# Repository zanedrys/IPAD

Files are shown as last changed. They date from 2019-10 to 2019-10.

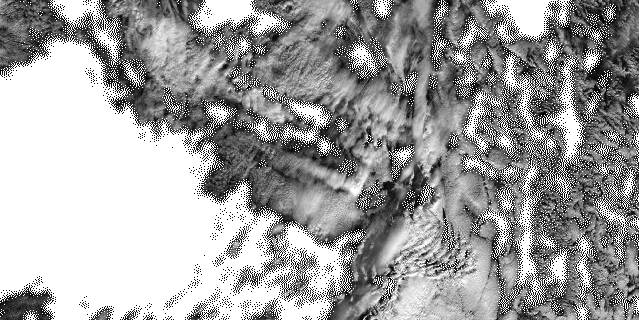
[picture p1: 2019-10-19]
Processing 2.2.1/processing-2.2.1/modes/java/examples/Books/Getting Started/media/clouds.gif

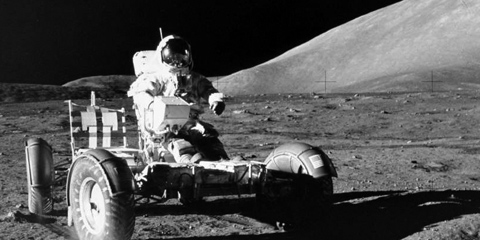
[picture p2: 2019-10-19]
Processing 2.2.1/processing-2.2.1/modes/java/examples/Books/Getting Started/media/lunar.jpg

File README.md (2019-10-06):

# IPAD
Interactive Programmable Arts Display

Getting Started - Testing Hardware,

  Below are the instructions to setup and test the hardware (CNC shield, Arduino, Stepper Motors, Drivers and various connections.

    1. Plug in necessary hardware, uno on arduino, 12v to cnc, steppers to cnc etc (See wiring diagram)
    2. Download and install Arduino IDE https://www.arduino.cc/en/main/software
    3. Download GRBL https://github.com/gnea/grbl/releases
    4. Download XLoader http://www.hobbytronics.co.uk/arduino-xloader
    5. Follow instructions to get GRBL on the Arduino/cnc
    6. Download Universal Gcode Sender https://winder.github.io/ugs_website/
    7. UGS should detect the CNC shield and any connected motors
    8. Plug and Play Away

Setting up a Gamepad/Joystick   
  Below are the methods to using a joystick/gamepad or any analog input method.
 
    1. Plug in necessary component
    2. Download and install Joys2Key https://joytokey.net/en/
    3. Download the library file 'JoyToKeyToPlotter.cfg' file (In repo)
    4. Import file to JoyToKey
    4. From within UGS (Universal Gcode Sender), use the joystick 

Setting up WASD Input Method (Any Input Is Possible)
  Below are instructions to create live Gcode to be sent to the UGS Command Line, highly configurable
  
    1. Download and Install AutoHotkey https://www.autohotkey.com/
    2. Download library file 'GcodeWASD.ahk' file (In repo)
    3. Run the file (Manipulate as desired for alternate inputs)
    4. From within UGS Command Line, use WASD to initiate movement

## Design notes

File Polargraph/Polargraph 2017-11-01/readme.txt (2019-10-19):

*  Polargraph Software
*
*  Written by Sandy Noble
*  Released under GNU License version 3.
*  http://www.polargraph.co.uk
*  https://github.com/euphy/polargraph

10th May 2017

This is the source code for the Polargraph software. 
It contains:

Controller v2.4.2
---------------

Binary (compiled) versions of the controller for

- 32 bit linux
- 64 bit linux
- 32 bit Windows
- 64 bit Windows
- MacOS

Along with source code for the controller in the processing-source 
folder.

It also includes the required Processing libraries (geomerative, Controlp5, 
Diewald CV kit) that the controller uses.  These are not necessarily
the most recent versions, but they are the versions that work.

Processing Libraries should be copied into the libraries subfolder in 
your Processing sketchbook folder.

This is written and compiled under Processing v2.2.1.  
It does not work in Processing 3.

Firmware
--------

* Server v1.2.1 for regular Polargraph (UNO, MEGA) machines.
* Server v1.4 for PolargraphSD machines.

Code has been tested in Arduino IDE 1.6.7.

The arduino-source folder has the code for the firmware that should 
be uploaded to your arduino.  There are currently two supported versions:

- polargraph_server_a1 for Arduino UNO- or MEGA-based machines, based on 
  Adafruit motorshields, or with serial stepper drivers (eg Easydriver, 
  stepstick etc) or signal amplifiers.

- polargraph_server_polarshield for Arduino MEGA 2560 running with 
  an attached Polarshield, serial stepper drivers and LCD touchscreen.

Each version is in it's own folder along with a precompiled .hex that
can be loaded directly using something like XLoader (some info about this
https://github.com/euphy/polargraph/wiki/Uploading-precompiled-binary-hex-files)

In the arduino-source folder there is also a libraries folder that
has all the arduino libraries that you will need to compile the 
firmware.

- AccelStepper
- AFMotor (for those using the Adafruit motor shield v1)
- Adafruit_MotorShield (for those using the Adafruit motor shield v2)
- UTFT (for the polarshield)
- UTouch (for the polarshield)

UTouch sometimes benefits from calibration, so if you find your 
touchscreen is not responding properly to your touch, you might 
need to do that.  The calibration figures that are in there already 
are ok for my ITDB02-2.4 screens.

The arduino libraries should be copied into your arduino sketch folder.

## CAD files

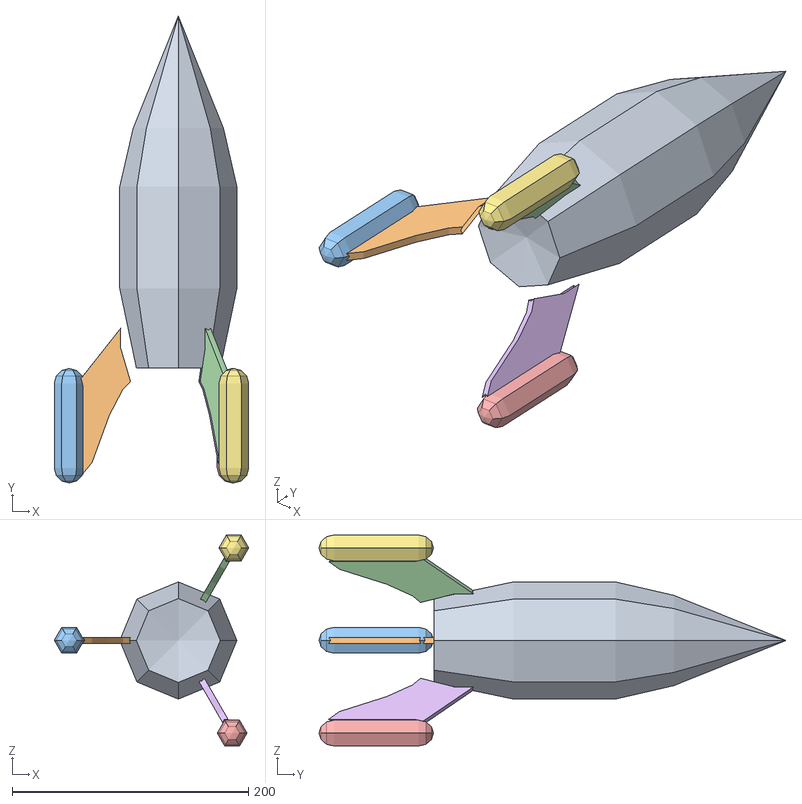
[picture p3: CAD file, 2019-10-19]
Processing 2.2.1/processing-2.2.1/modes/java/examples/Basics/Shape/LoadDisplayOBJ/data/rocket.obj
164.8 x 395.7 x 178.8
Rocket
wing01
reactor01
wing02
reactor03
wing03
reactor02

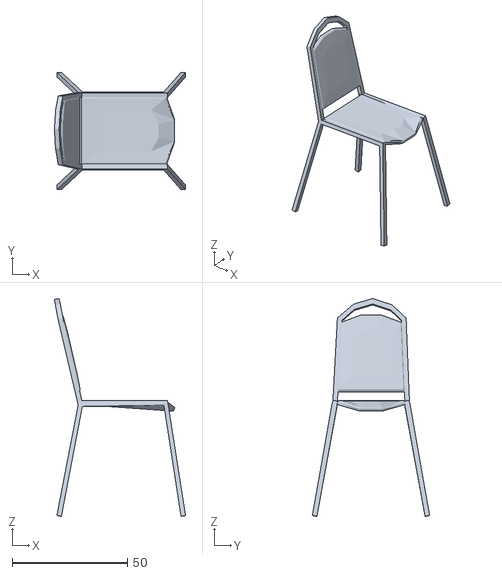
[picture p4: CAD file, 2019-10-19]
Processing 2.2.1/processing-2.2.1/modes/java/examples/Books/Processing Handbook/Extensions/3D/Ex_05/data/chair.obj
56.8 x 50.7 x 94.4

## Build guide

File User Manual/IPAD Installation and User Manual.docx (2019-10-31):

# Interactive Programmable Arts Display

# V Plotter Installation and User Manual

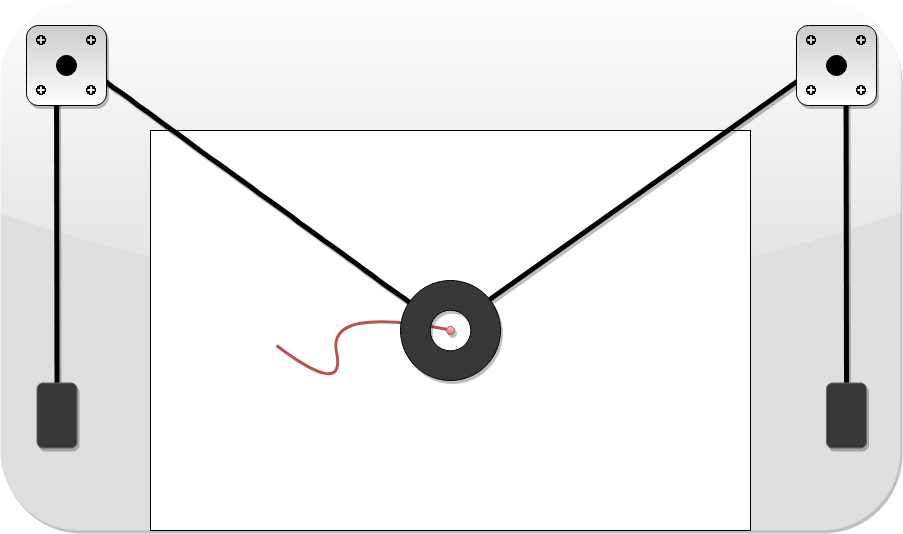
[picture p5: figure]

Version | Date | Description | Author
1 | 24/10/2019 | Initial creation | Zane Drysdale – zjdrysdale@gmail.com
2 | 26/10/2019 | Firmware and software Instructions update | Zane Drysdale – zjdrysdale@gmail.com Corey Page – Corey.t.page@outlook.com.au
3 | 27/10/2019 | 5.1 .1 Values update | Corey Page – Corey.t.page@outlook.com.au
4 | 27/10/2019 | Team Signoff | Zane Drysdale – zjdrysdale@gmail.com Corey Page – Corey.t.page@outlook.com.au Franklin Moon – Franklin.m.moon@gmail.com Zinan Chen–

# 1 Introduction and Purpose

A V Plotter is a drawing robot which uses two motors to move a hanging writing implement across a drawing surface.

The purpose of this document is to provide a complete end-to-end guide for the creation of the V Plotter, including hardware requirements as well as software installation, configuration, usage, and troubleshooting.

This complete solution is reliant upon three distinct yet interrelated subsets. The hardware which is the physical canvas, motor and electronics setup, the Windows/Linux software which handles end user input, and the Arduino firmware which interprets commands from the software and controls the motors. This document details the installation and configuration of all three of these subsets as part of the overall solution.

This document is targeted towards anyone who wishes to set up the V Plotter and has basic computing knowledge. This guide presumes that you are setting up the V Plotter with the hardware as provided, however, additional notes cover alternative implementations or possible modifications or options.

Some steps require caution, this information is in red.

# 2 Hardware

The physical aspects of the V Plotter consist of the motors and the board that they are mounted to, as well as the belts and physical electrical and computer hardware. The below diagram details at a high level the basic physical components:

The

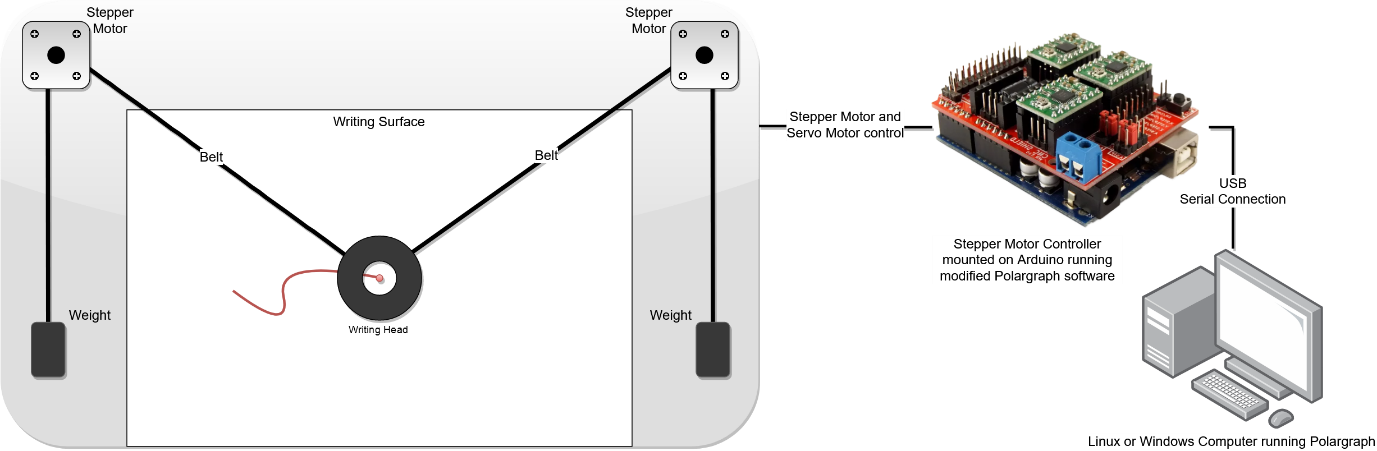
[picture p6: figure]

Figure 1: Overall V Plotter setup

## 2.1 Components

The V Plotter as delivered consists of the following required and supplied hardware components:

- Machine surface – overall surface that the motors are mounted to
- Writing surface
- 2 NEMA stepper motors. 200 steps per revolution.
- Official Arduino UNO loaded with modified Polargraph firmware
- Stepper Motor Controller – Specifically the Protoneer CNC Shield V3: https://blog.protoneer.co.nz/arduino-cnc-shield
- 12V 1 Amp DC Power supply
- Belts and suitably toothed and spindled gears
- Microsoft Windows based computer running Polargraph
- 3D printed motor mounts
- Associated wiring for motors

The main components are further detailed as follows:

### 2.1.1 Arduino UNO

The Arduino is responsible for translating the commands sent over USB from the Polargraph application into electrical signals to the stepper motor controller. As such, the Arduino and stepper motor controller are highly dependent upon one another.

### 2.1.2 Stepper Motor

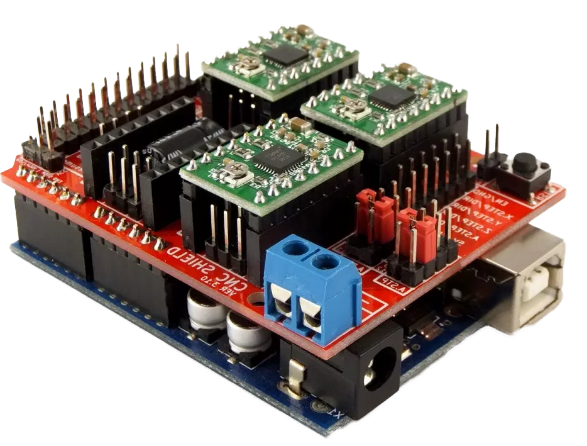
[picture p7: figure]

The stepper motor driver is responsible for actuating the motors as required, and electronically separating logic and power for safety and durability. The Protoneer stepper motor is typically used for three-axis CNC machines. The Protoneer stepper motor provided is designed to be directly compatible with an Arduino UNO, and sits directly on top, interfacing with the Arduino outputs directly, as shown in Figure 2:

### 2.1.3 Power Supply

Figure 2. Stepper Motor Controller mounted on top of an Arduino UNO

Responsible for providing power to the stepper motor controller. Simply plugs into the DC female terminal on the Arduino, also visible in Figure 2.

## 2.2 Hardware Setup

This section details the physical installation of the components.

The physical installation is provided pre-assembled and will require minimal setup or extra assembly. However, if assembly is required:

### 2.2.1 Writing Head

The writing head is the device which sits hung across the drawing surface. It holds the pen or other writing implement and is supported and moved by the belts.

1. Place the pen into the centre of the writing head and tighten the threads to secure it in place. It is imperative that the tip of the pen only minimally protrudes from the underside of the writing head to improve accuracy
2. Affix the belts around the mounts on the corners of the writing head
3. Mount the servo motor into the top of the writing head

### 2.2.2 Stepper Motors

The motors are responsible for moving the writing head by lengthening or shortening the amount of belt between the motor and writing head.

1. Ensure that the motors are bolted to their mounts
2. Bolt each mount to the machine surface
3. Plug in the motor-end of the supplied wiring
4. Run the belt atop the gear to form the overall ‘V’ shape, as in Figure 1
5. Affix the weights to the end of the belt

### 2.2.3 Servo Motor

The servo motor is responsible for raising and lowering the pen off the page. It is connected to the stepper motor controller in our solution. Refer to Appendix 3 for the wiring diagram.

1. Plug the RED wire of the servo into the +5V output on the Protoneer. This is the power for the servo.
2. Plug the BROWN wire of the servo into the BLACK side of the CooEn pin on the Protoneer. This is the ground for the servo.
3. Plug the ORANGE wire of the servo into the WHITE side of the CooEn pin on the Protoneer. This is the signal for the servo.

### 2.2.4 Arduino and Stepper Motor Controller

As detailed in their sections above, the Arduino and stepper motor controller are responsible for receiving commands over USB and driving the motors. The Protoneer stepper motor controller sits directly atop the Arduino as shown in Figure 2. Refer to Appendix 3 for the wiring diagram.

1. Sit the Protoneer stepper motor controller atop the Arduino as depicted in Figure 2.
2. Plug the other end of the previously attached motor wires into the stepper motor controller X and Y outputs, such that the left motor is plugged into the ‘X’ output, and the right motor is plugged into the ‘Y’ output. Take note of the direction that the cables are plugged in; the lip on the connector is facing the motor shields of their respective outputs, as visible below in Figure 3

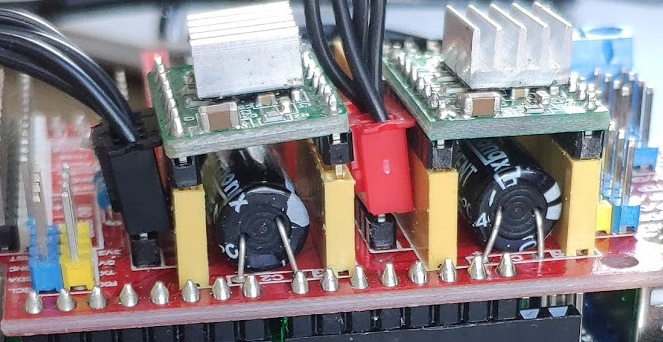
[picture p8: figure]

Figure 3: Motor wiring on stepper controller

### 2.2.5 Power Supply

Caution: Although the supplied power supply has a low risk of electric shock, be careful to ensure that it is not shorted, it could hurt or even worse break something.

Caution: Never cut power to the stepper motor controller while the V Plotter is in operation or holding the motors’ position, as it can damage the stepper motor controller.

- Plug the output of the power supply into the female DC power input of the Arduino, as visible in Figure 2

## 2.3 Modifications or Customizations

The V Plotter is designed to be easily modular and flexible to alternative physical implementation with only a software reconfiguration required. However:

- Increasing the size of the machine considerably may require motors with additional torque and larger sprockets, and possibly in turn a higher-output power supply.
- Alternative stepper motor controllers are possible; however, as detailed in the below section, the Arduino firmware may require customization to modify the output pins to match the alternative stepper motor controller.

# 3 Firmware

The firmware is responsible for receiving the commands from the Polargraph application running on a computer and sending the correct electrical signals to drive the stepper motor controller. It interprets ASCII commands sent over the USB connection from the Polargraph application running on a computer.

This solution uses the Polargraph firmware and associated end user application from polargraph.uk. This step covers the firmware half.

The Polargraph firmware expects an alternative stepper motor controller and therefore our solution includes a modified version of the firmware that supports the Protoneer stepper motor controller. 3.2 details how to install this modified firmware, or you can follow 3.3 to modify the firmware from source.

This step details how to modify and load the firmware on the Arduino if required. As delivered, the Arduino is already loaded with the modified firmware.

## 3.1 Requirements

The modified firmware as delivered is intended for an Arduino UNO and the Protoneer stepper motor controller pairing. The firmware can be installed from a Windows, Linux, or Mac computer. The modifications made to the source include:

- Manual configuration of the stepper motor output pins on the Arduino to match the expected inputs on the Protoneer stepper motor controller.
- Manual configuration of the Pen lift pin, to allow the signal to be passed through to Protoneer stepper motor controller via the “Coolant Engage” pin, using the A3 pin on the Arduino.

It would be best to clone or download the IPAD repo (http://github.com/zanedrys/IPAD) to ensure that you have the firmware and software required for the following steps.

## 3.2 Installation – Custom Firmware

1. Firstly, install the Arduino IDE from arduino.cc for your platform
2. Download the modified firmware from GitHub: https://github.com/zanedrys/IPAD/tree/master/Polargraph/Polargraph%202017-11-01/modified%20arduino-source, or even better clone the repository for future use.
3. Included are the Arduino libraries that are required and known to work to compile the source code. Copy the files in the “libraries” folder into your Arduino Sketch directory, or alternatively add them to your Libraries from the Arduino IDE.
4. Open the “polargraph_server_a1” sketch in the Arduino IDE.
5. Verify the sketch to ensure that it compiles:

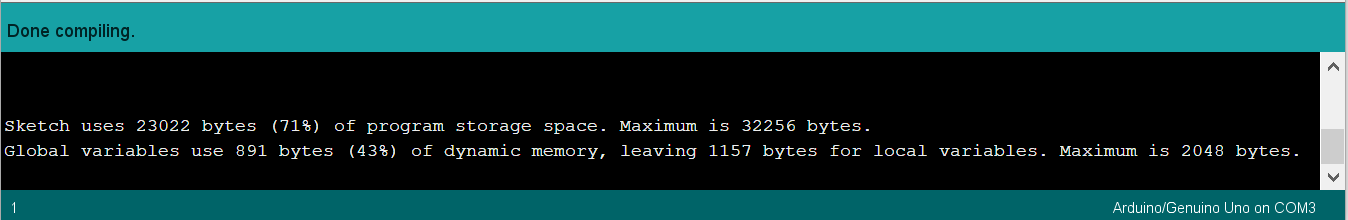
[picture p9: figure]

6. Plug the Arduino into your computer with a USB cable, and wait until the drivers are installed.
7. Within the Arduino IDE, check that your Arduino is connected. Under ‘Tools’ -> ‘Port’, the Arduino should be listed.
8. Click the arrow to upload the firmware to the Arduino:

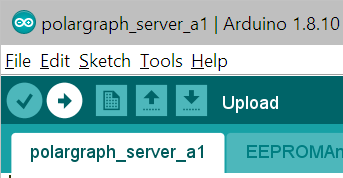
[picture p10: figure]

9. The Arduino IDE should tell you that the firmware was successfully flashed.

## 3.3 Modifying firmware from source

This step is not necessary if you flashed the custom firmware from the previous step.

If you wish to modify the firmware yourself, the Polargraph firmware can be modified to work with a variety of stepper motor controllers:

- The Adafruit Motorshield v1 and v2
- Generic serial stepper drivers
- Four-wire signal amplifiers

By default, the source Polargraph firmware is designed to be used with an Adafruit stepper motor. The Protoneer stepper motor controller used in this solution is a generic serial stepper driver at core. Therefore, the source firmware must be modified to work with the Protoneer. Below are the steps required to modify the firmware from source with examples for the Protoneer controller in particular:

1. Download the source Polargraph firmware from GitHub: https://github.com/euphy/polargraphcontroller/releases/
2. Install the Arduino IDE from arduino.cc for your platform
3. Included within the “arduino_source” directory are all the files required. Copy the files in the “libraries” folder into your Arduino IDE Sketch directory, or alternatively add them to your Libraries from the Arduino IDE
4. Open the “polargraph_server_a1.ino” sketch in Arduino IDE. It is commented well with instructions. Instructions specifically for the Protoneer follow:
5. Specify the custom motor driver:
  a. Comment out lines within section 3i, as this solution does not use the Adafruit:

// i. Adafruit Motorshield v1. The original, and still the best.

// #define ADAFRUIT_MOTORSHIELD_V1

// #include <AFMotor.h>

  b. Uncomment out lines within section 3ii, as this solution uses a discrete stepper driver:

// iii. Using discrete stepper drivers? (eg EasyDriver, stepstick, Pololu gear)

// ----------------------------------------------------------------------------

// Don't forget to define your pins in 'configuration.ino'.

#define SERIAL_STEPPER_DRIVERS

  c. Change the output pin for the Pen Lift to A3 as in the following block of code.

// Pen raising servo

Servo penHeight;

const int DEFAULT_DOWN_POSITION = 90;

const int DEFAULT_UP_POSITION = 180;

static int upPosition = DEFAULT_UP_POSITION; // defaults

static int downPosition = DEFAULT_DOWN_POSITION;

static int penLiftSpeed = 3; // ms between steps of moving motor

const byte PEN_HEIGHT_SERVO_PIN = A3; //Change the servo pin to A3, to pass through to the coolant enable pin.

boolean isPenUp = false;

  d. Configure the Arduino output pins in ‘configuration.ino’ as follows, to match the Protoneer. To see where we got these pins are from, refer to Appendix 2 for the Protoneer pinout:

#ifdef SERIAL_STEPPER_DRIVERS

#define MOTOR_A_ENABLE_PIN 8

#define MOTOR_A_STEP_PIN 2

#define MOTOR_A_DIR_PIN 5

#define MOTOR_B_ENABLE_PIN 4

#define MOTOR_B_STEP_PIN 3

#define MOTOR_B_DIR_PIN 6

AccelStepper motorA(1,MOTOR_A_STEP_PIN, MOTOR_A_DIR_PIN);

AccelStepper motorB(1,MOTOR_B_STEP_PIN, MOTOR_B_DIR_PIN);

#endif

6. Follow the instructions for 3.2 Installation – Custom Firmware to install the modified firmware.

# 4 Software

This solution uses the Polargraph firmware and associated end user application from polargraph.uk. This step covers the installation of the application half.

The application is responsible for providing an end-user graphical interface and sending commands to the firmware running on the Arduino. It can load vector and bitmap images.

## 4.1 Requirements

The Polargraph application is written in Processing 2.2.1 and requires the Java Runtime Environment to run.

Processing is compatible with Windows (32/64 bit), Linux (32/64 bit), and Mac OSX. Therefore, Polargraph can only run on those platforms.

## 4.2 Installation

Included in the GitHub repository are pre-compiled versions of the Polargraph application: “IPAD\Polargraph\Builds”.

1. Copy the suitable folder for your system to a suitable location. The binaries are available in Linux and Windows, each in 32-bit or 64-bit versions. The Windows 64-bit version includes its own Java Runtime Environment, otherwise ensure that you have the Java Runtime Environment installed.
2. Run the suitable binary for your system.
3. After a minute or so on first run the application should start. If it doesn’t and Java is installed, it may be necessary to run it from source. Refer to section 4.3 below:

## 4.3 Run from Source

Java, Windows, and Processing may not work as expected on some machines. In this case the Polargraph software can be run from source code. This method can also be used if the Polargraph software receives an update, or if you wish to modify the source code or debug the application.

1. Download Processing 2.2.1 from processing.org (https://processing.org/download/?processing). Ensure to download the version with Java included. Alternatively, Processing 2.2.1 is included in the GitHub repo.
2. Install Processing to a suitable folder and run it. Processing calls applications “sketches”, and your Sketchbook folder is where they are stored. On Windows, it is the Processing folder within the user’s Documents folder. If you need to find out where your sketchbook is, then you can open Processing, and go file->preferences and it'll tell you your Sketchbook location at the top of the dialog box. The folder might not get created until you run Processing once.
3. Download code from the repo https://github.com/euphy/polargraphcontroller/releases/latest and download the package. Alternatively download the version from our repo: https://github.com/zanedrys/IPAD/tree/master/Polargraph/Polargraph%202017-11-01/processing-source
4. Copy the entire ‘polargraphcontroller’ folder into your Processing sketch folder. E.g. ‘Documents/Processing/polargraphcontroller’
5. Copy the folders within the ‘Processing libraries (https://github.com/zanedrys/IPAD/tree/master/Polargraph/Polargraph%202017-11-01/processing-source/Processing%20libraries)’ folder into the Processing ‘libraries’ folder, not the folder itself.
6. The folder structure therefore after these changes (shown in bold) should look like:
  - Processing/
    - libraries/
      - ControlP5/..
      - diewald_CV_kit/..
      - geomerative/..
    - polargraphcontroller/
7. From the ‘File’-> ‘Sketchbook’ option in Processing, open the polargraphcontroller sketch:

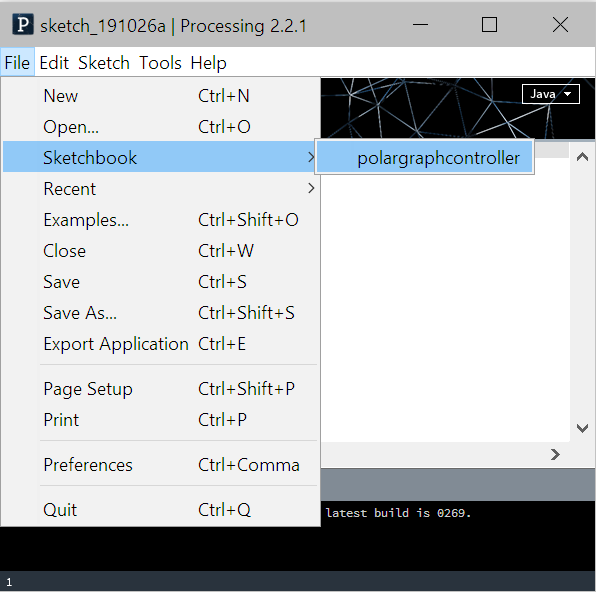
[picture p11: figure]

8. Run the sketch and the Polargraph application should start.

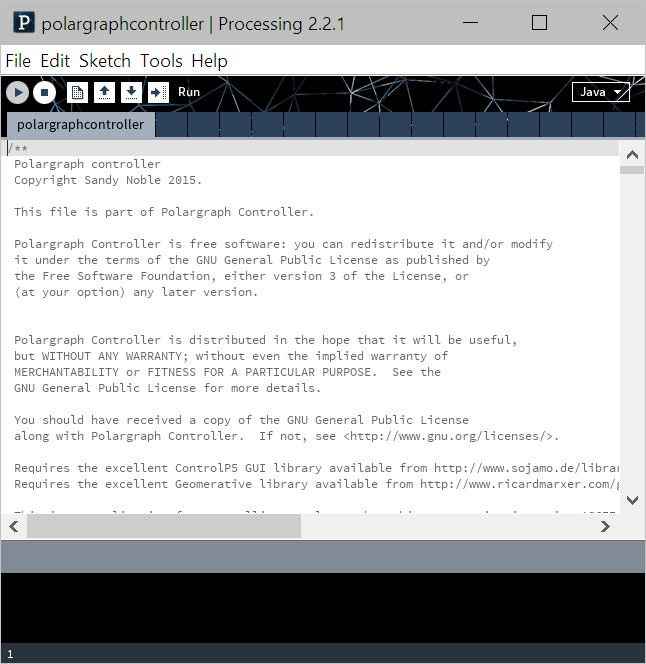
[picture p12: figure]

9. Congratulations, the Polargraph application should now be running.

## 4.4 Compile from Source

After completing the steps in 4.3 – Run from Source, you can create your own build of the Polargraph application. This might be especially helpful if the pre-compiled version supplied did not start, and you had to run the application from source as above.

1. Open the sketch in Processing as detailed in 4.3 – Run from Source
2. Go ‘File’ -> ‘Export Application’:
3. Choose the platforms to compile for, and whether to include Java in the Windows 64-bit build if applicable. Click Export:

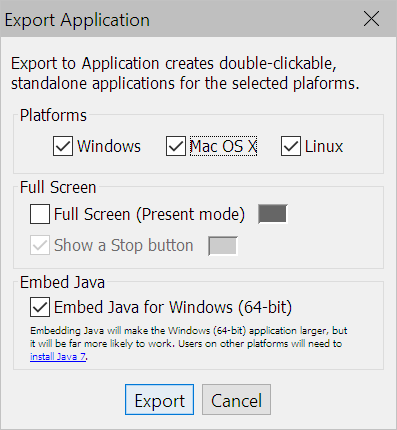
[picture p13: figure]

# 5 Configuration

Now that the hardware is set up, the Arduino is running the firmware, and the software is running on computer, it is time to set up the Polargraph software to finally draw. Below is a checklist to go through to ensure that the V Plotter is ready.

Pre-Flight Checklist:

1. Check that the board and surface is set up, and the belts and writing head are set up.
2. Check that the motors are correctly plugged into the motor controller.
3. Check that the stepper motor is correctly plugged into the top of the Arduino.
4. Ensure that the Arduino is connected to your computer over USB, and that it is powered on.
5. Plug in the power adaptor and turn the switch on.

## 5.1 Configure Polargraph application

### 5.1.1 Physical Attributes

The Polargraph application needs to know the following information about the physical setup to draw accurately. This information is entered into the ‘Setup’ page, as shown in 6.1.2 – Setup Page.

- Steps per Rev: How many steps your stepper motors require to make a complete revolution. As delivered, the motors require 200 steps per revolution.
- mm per rev: How much belt is let in or out per revolution of the stepper motor. As delivered, this is 50 mm. To calculate this yourself simply find the circumference of your sprocket.
- Motor Step Multiplier: How many micro-steps your motor controller makes per full step of the motor. Stepper motor controllers can increase the resolution of your motors by using micro stepping. As delivered, the Protoneer is not performing micro stepping.
- Machine Width in mm: The physical width of the machine, refer to Figure 4: Machine Dimensions. As delivered, this is 724 mm.
- Machine Height in mm: The physical height of the machine. Refer to Figure 4: Machine Dimensions. As delivered, this is 480 mm.
- Page Width: The width of the drawing area available to be drawn on. Naturally, this must be smaller than your machine width. Allow for some buffer as the V Plotter will be increasingly less accurate the closer it attempts to draw to the motors. As delivered, this is 600mm
- Page Height. The height of your page. This must also be small than your machine height and have buffer between the height of the motors and the top of the page. As delivered, this is 400mm.
- Page Pos X: Where the page sits horizontally. Polargraph can set this to be in the centre of your machine. As delivered, this is 150 mm.
- Page Pos Y: How far below the machine top that the page sits. Again, this cannot be too close to the top of the machine. As delivered, this is 130 mm.
- Home Pos X/Y: Where the physical position of the writing implement is aligned with the start position. This is required so that Polargraph knows where the writing head is. Polargraph can automatically set this to be the top centre of your page. It can be wherever you like, if you can accurately manually place the writing head in that location.
- Motor Max Speed: The maximum speed that the machine will move the motors. Have this too low, and the motors will move very slowly, and your drawing will take a long time to complete. Have this too high, and you may encounter the belt hopping on the sprocket, which will ruin your image. 100
- Motor Acceleration: How quickly the motors will accelerate up to the Motor Max Speed. Have this too high and the belt may hop on the sprocket while the machine is accelerating from a stop, or from changing direction. Have this too low, and your machine may never reach its Motor Max Speed. 80
- Pen Up Position: The angle that the machine will hold the servo at when the pen is up. 70mm
- Pen Down Position: The angle that the machine will hold the servo at when the pen is down. 187 mm
- Pen Thickness: Determines how many lines the V Plotter can fit into an area. If you have a pixel that is 20mm square, and you have a 1mm pen tip, then you can only fit a maximum of 20 lines in before it's at its maximum density. Adding more ink then won't make it any darker. You can change the pen width on the setup tab, by changing the value of pen tip size and clicking send pen tip size. The tip size is not saved in the machine, it needs to be resent every time the machine is restarted, which is why the value is pre-loaded in the queue when you restart the controller.

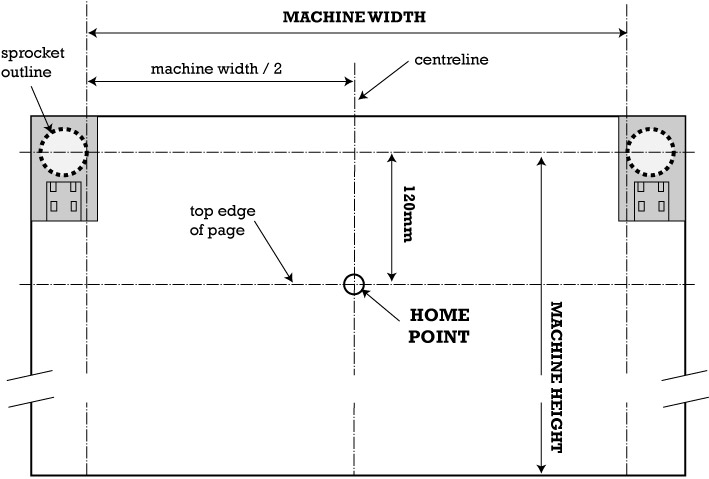
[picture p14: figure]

Figure 4: Machine Dimensions

### 5.1.2 COM Configuration

The Polargraph application communicates with the Arduino firmware over a USB COM port. To set the COM port in the Polargraph application, go to ‘Setup’->’Serial Connection’, and choose your COM port. It can be best to restart Polargraph after changing this option.

The Polargraph application will display ‘Polargraph Ready! (Uno)’ when the Arduino is successfully connected:

# 6 User Guide

This section of the Manual will cover the usage of the application and presumes that the machine is set up with the information presented thus far.

## 6.1 Navigating the Application

The Polargraph application is used through the following three views:

### 6.1.1 Input:

Input vectors, drawing and lines to be drawn.

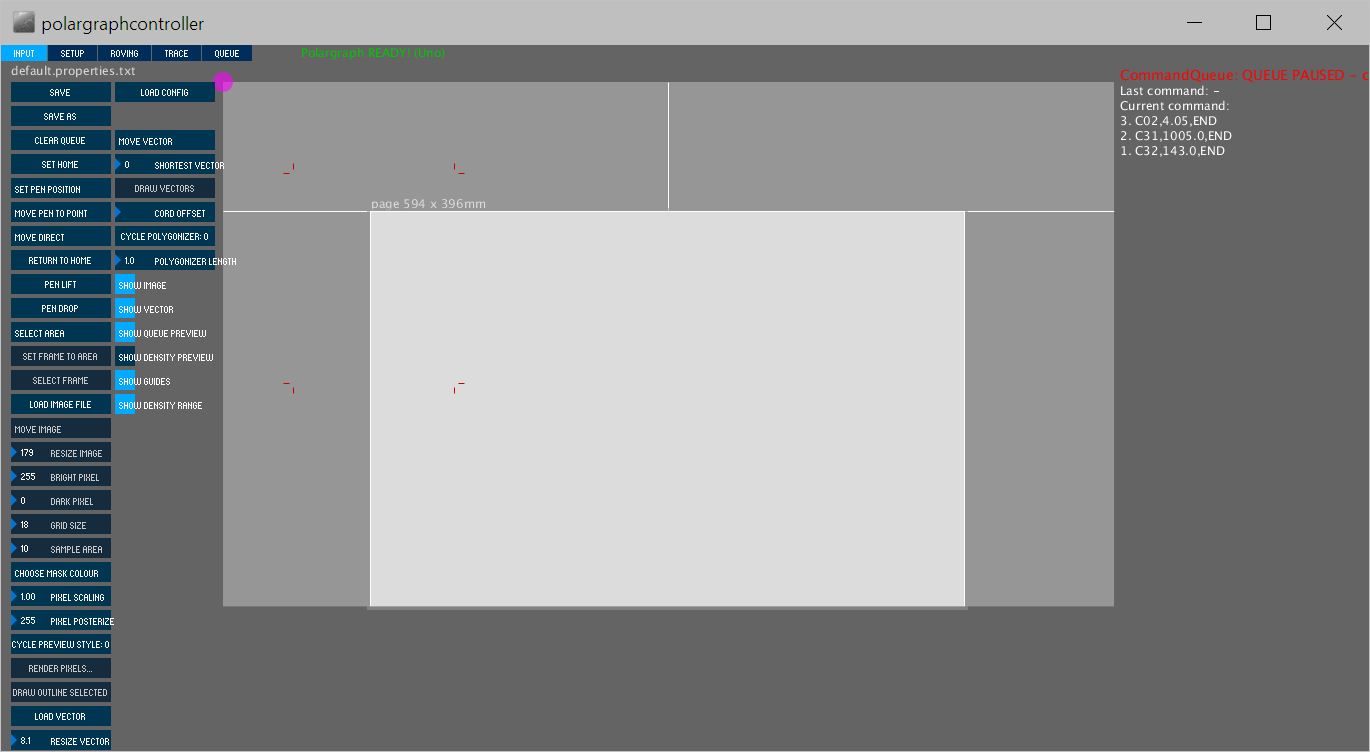
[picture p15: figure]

### 6.1.2 Setup

Sets up the machine configuration.

- Input the values from 5.1 – Configuring Polargraph Application into this screen.
- Ensure to click ‘Upload Machine Spec’ with the queue running to send the updated settings to the Arduino.
- You can ‘Centre Page’ to place the page in the middle of the machine.
- You can ‘Centre Homepoint’ to place the home position at the top middle of the page.
- You can also export and load these settings with ‘Save As’ and ‘Load Config’.
- Ensure to click ‘Save’ to save these settings for the Polargraph application.

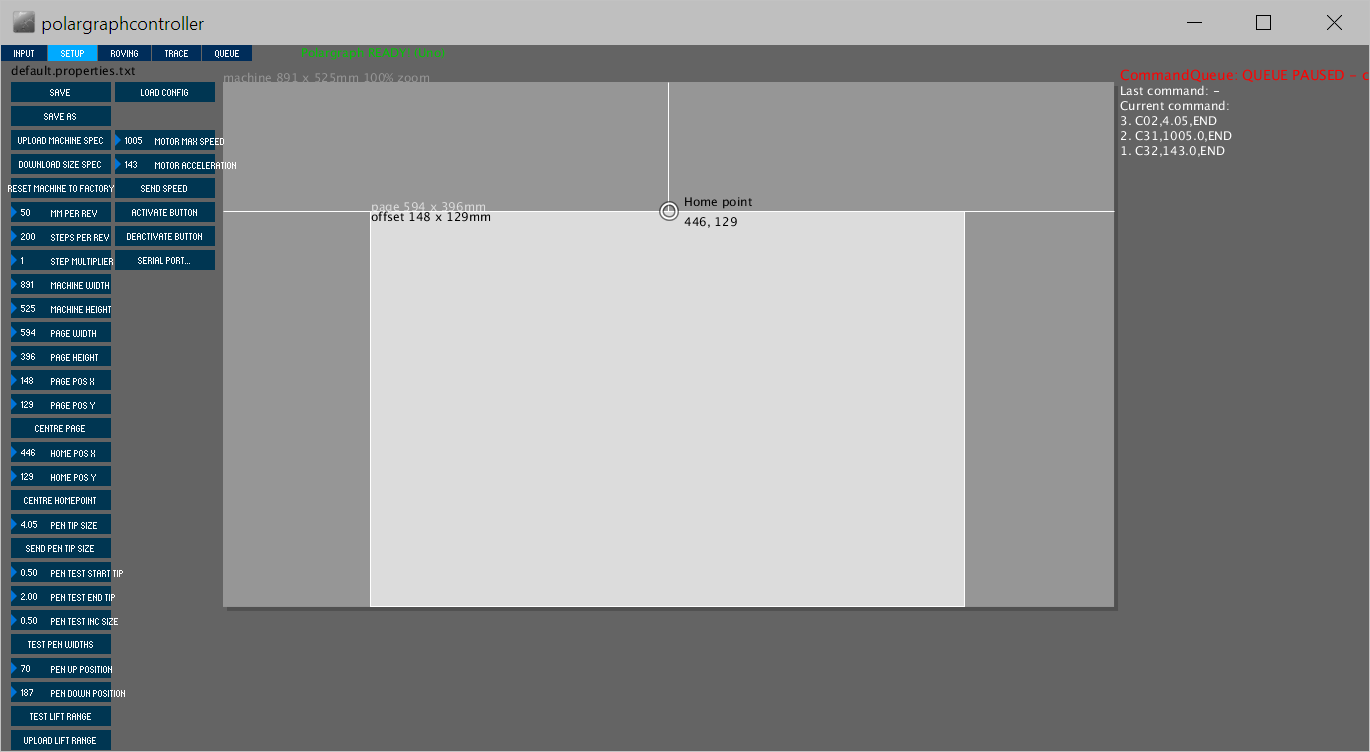
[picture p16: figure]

### 6.1.3 Trace

Used to convert bitmaps to vectors.

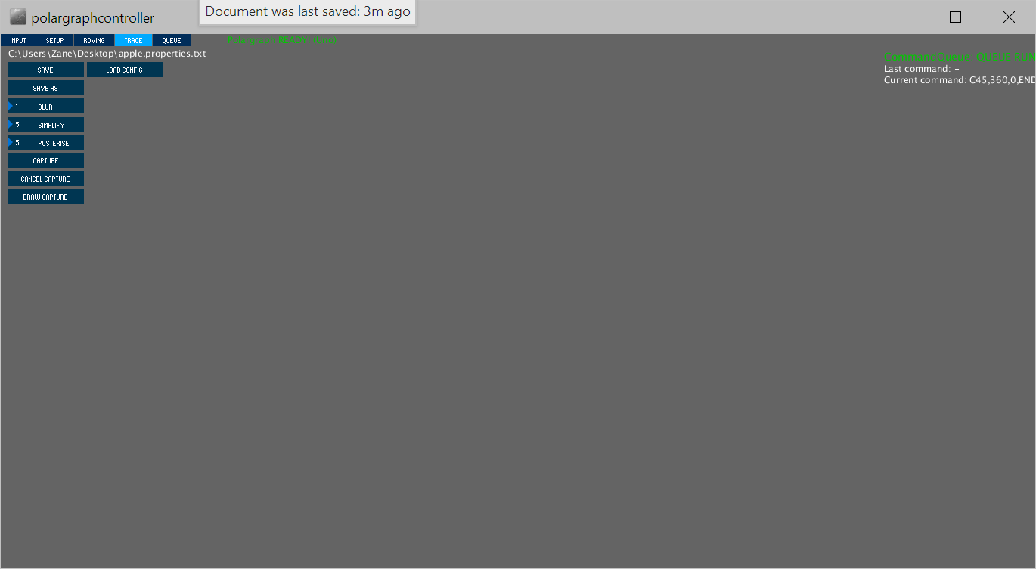
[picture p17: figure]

### 6.1.4 Queue

Used to export and import the command queue.

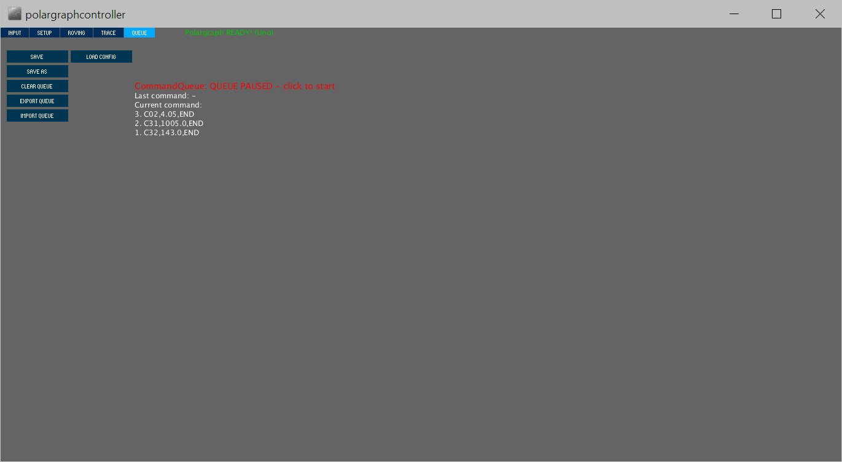
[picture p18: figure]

## 6.2 Drawing

### 6.2.1 Queue

As visible in the screenshots above, there is a queue to the right. This list contains the list of commands that will be sent to the Arduino. On start-up, this queue is in a Paused state, and will not send commands to the Arduino. To un-pause it, simply click the Command Queue text.

### 6.2.2 Homing

The V Plotter needs to be homed on start-up, so that Polargraph knows the physical location of the writing head. Manually move the drawing head to be over the Home location set in Polargraph, then on the ‘Input’ page, click ‘Set Home’. Ensure that the queue is running. The motors will both turn and lock in the current location.

### 6.2.3 Manually Moving

You can manually move the writing head around the page and raise and lower the pen as desired.

- Click ‘Move Pen to Point’ and click on the canvas to move the pen to a point on the drawing surface.
- Click ‘Raise Pen’ and ‘Lower Pen’ to manually raise and lower the pen with the servo.
- Click ‘Return to Home’ to move the pen back to home.

### 6.2.4 Draw a Vector

Vector images are well-suited to work with Polargraph. To draw a vector image, from the ‘Input’ page:

1. Set Frame:
  a. Click ‘Select Area’ and select the entire page.
  b. ‘Set Frame to Area’ to allow the vector to be drawn within the selected area.
2. Load Vector
  a. Click ‘Load Vector’ and choose your vector image.
3. Place Vector
  a. Click ‘Move Vector’ and click on the page where you want the vector to be drawn.
  b. Drag ‘Scale Vector’ to scale the vector to the intended size.
4. Choose Shortest Vector
  a. Increase the ‘Shortest Vector’ amount to increase the minimum length of line that is drawn. If it’s too low, the pen will move very slowly.
5. Draw!
  a. Click ‘Draw Vectors’ to load the commands to draw the vector into the queue.
  b. Ensure that your Queue isn’t paused, and the machine will start drawing the vector.

### 6.2.5 Draw a Bitmap

There are two ways to draw bitmaps. It can detect and draw lines from an image, or it can draw pixels.

### 6.2.6 Draw shaded pixels from an Image

This method samples an image, and then draws the pixels.

- Load and Sample Image:
1. Click ‘Load Image File’ and select your PNG or JPG image.
2. Click ‘Move Image’ to place the image where you want on the page.
3. Click ‘Resize Image’ to scale the image to the size that you want.
4. Click ‘Select Area’ to select the area of the canvas to sample. You will now have a preview of how the image will be sampled.
5. Adjust the ‘Dark Pixel’ and ‘Bright Pixel’ settings to limit the brightest and darkest pixels to be sampled.
6. Adjust the ‘Grid Size’ to choose how fine to sample the pixels.
7. Adjust the ‘Sample Area’ to choose the area of pixels to be sampled against the grid.
- Render Pixels
  1. Click ‘Render Pixels’
  2. Choose the direction to start from, as well as the shading style
  3. Click ‘Render’ and the commands will be generated and placed into the queue, ready to be printed.

### 6.2.7 Trace lines from an Image

This method detects lines within an image, and then draws them.

- Load Image:
1. Click ‘Load Image File’ and select your PNG or JPG image.
2. Click ‘Move Image’ to place the image where you want on the page.
3. Click ‘Resize Image’ to scale the image to the size that you want.
- Trace Image
  4. Move over to the ‘Trace’ tab. You will see your image has now been traced.
  5. Adjust the ‘Blur’, ‘Simplify’ and ‘Posterise’ options to define the trace
  6. Click ‘Capture’ to capture the trace
  7. Click ‘Draw Capture’ to send the commands to the queue, ready to be printed.

# 7 Troubleshooting

Issue | Solution
1. Commands aren’t running/V Plotter isn’t moving | - Check that the queue isn’t paused. - Refer to Issue 2.
2. Polargraph “isn’t connected” error | - Change the COM port under ‘Setup’ to another port. Ensure to click OK. Restart Polargraph.
3. V Plotter isn’t moving as expected: | - If the V Plotter movement appears horizontally inverted but not vertically inverted, the motors are plugged into the wrong outputs and have their wiring reversed. - Swap the motors on the stepper motor to the opposite output and flip the connectors. - If the V Plotter movement appears vertically inverted but not horizontally inverted, the motors need to be swapped. - Swap the motors on the stepper motor to the opposite output
4. The belt is skipping teeth under acceleration | - Check that the weights are attached - Lower the “Acceleration” rate in the setup window of Polargraph.
5. The belt is skipping teeth at speed | - Check that the weights are attached - Lower the “Max Speed” option in the setup window of Polargraph.
6. V Plotter moves too slowly | - Increase your ‘Max Motor Speed’ and your ‘Motor Acceleration’ settings. - If it is moving slowly drawing vector images: - Increase the “Shortest Vector” setting on the ‘Input’ page.

# 8 Glossary

Term: | Definition:
V Plotter: | The overall solution. Uses two stepper motors to move a writing head.
Polargraph: | Refers to the specific software and firmware implementation used in the solution: https://github.com/euphy/polargraph
Arduino | Refers to the Arduino UNO, a small single-board microcontroller that in this implementation runs the Polargraph firmware.
Arduino IDE | The Integrated Development Environment used to write code and upload it to the Arduino. Runs on Windows, Mac OS X, and Linux. The Polargraph firmware is written and loaded within the Arduino IDE.
Processing | The sketchbook language that Polargraph is written in.
Stepper Motor | A motor that divides a full rotation into a number of steps (in this implementation, 200), allowing the position of the motor to be precisely commanded and known.
Stepper Motor Controller | The hardware that controls the stepper motor. In this implementation, a “Protoneer CNC Shield V3” which is controlled by the Arduino.
Machine Width | The height of the machine from the centre of the motors, to the base.
Machine Height | The width of the machine between the inside of the sprockets.
Page Width | The width of the usable drawing space. Allow buffer.
Page Height | The height of the usable drawing space. Allow buffer.
Home | An initial known point on the board that the Polargraph software bases its movement around. The writing head must be moved to this point.

# 9 Appendices

## 9.1 Appendix 1: Additional Resources:

Our GitHub Repository: https://github.com/zanedrys/IPAD

The official Polargraph GitHub Repository: https://github.com/euphy/polargraph

## 9.2 Appendix 2: Protoneer Stepper Motor

Board Layout imposed upon an Arduino UNO. Useful in the modification of the Arduino pins in the firmware:

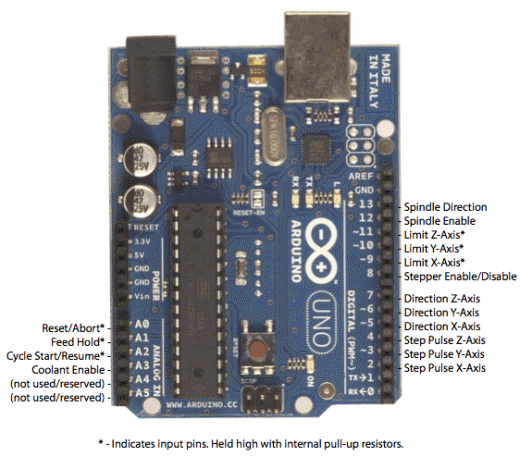
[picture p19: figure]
GRBL Pin Layout

## 9.3 Appendix 3: Motor Wiring Diagram

The motor wiring used with the Stepper Motor Controller.

The servo is driven off the Coolant Enable Pin, which the Arduino drives through Pin A3.

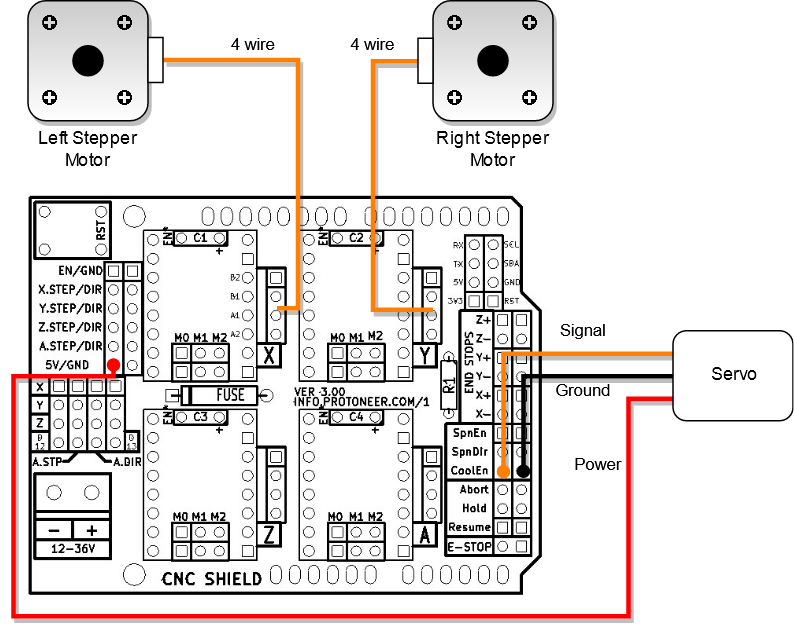
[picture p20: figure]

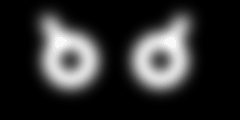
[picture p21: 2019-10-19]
Processing 2.2.1/processing-2.2.1/modes/java/examples/Books/Getting Started/media/frame-0008.png

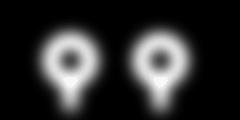
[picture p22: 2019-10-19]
Processing 2.2.1/processing-2.2.1/modes/java/examples/Books/Getting Started/media/frame-0003.png

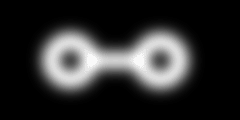
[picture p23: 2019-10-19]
Processing 2.2.1/processing-2.2.1/modes/java/examples/Books/Getting Started/media/frame-0000.png

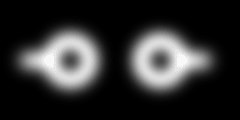
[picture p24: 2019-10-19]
Processing 2.2.1/processing-2.2.1/modes/java/examples/Books/Getting Started/media/frame-0006.png

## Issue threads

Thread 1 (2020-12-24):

configuration.ino has incorrect MOTOR_B_ENABLE_PIN setting

Joe321, 2020-12-24:
The MOTOR_B_ENABLE_PIN is incorrectly set as digital pin 4 in configuration.ino.  The CRC Shield V3 that the Protoneer implements only has one configuration pin, which is digital pin 8.  MOTOR_A_ENABLE_PIN correctly controls pin 8 and sets it high, allowing the software to be functional.  Digital pin 4 is the Z-drive step pin, which Appendix 2 of your documentation correctly shows.

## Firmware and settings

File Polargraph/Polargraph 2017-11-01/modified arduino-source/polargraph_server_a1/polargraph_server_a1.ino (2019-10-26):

/**
*  Polargraph Server for Arduino UNO and MEGA compatible boards.
*  Written by Sandy Noble
*  Released under GNU License version 3.
*  http://www.polargraph.co.uk
*  https://github.com/euphy/polargraph_server_a1


CONFIGURATION!! Read this! Really.
==================================

Kung fu is like a game of chess. You must think first! Before you move.

This is a unified codebase for a few different versions of Polargraph Server.

You can control how it is compiled by changing the #define lines below.

There are five config sections:
1. Specify what kind of controller board you are using
2. Add some libraries if you have a MEGA
3. Specify what kind of motor driver you are using:
  i. Adafruit Motorshield v1
  ii. Adafruit Motorshield v2
  iii. Discrete stepper drivers (eg EasyDriver, stepstick, Pololu gear).*
  iv. Signal amplifier like a UNL2003*
4.  Turn on some debugging code
5.  Disable program features if you need to free up space

* For motor drivers iii and iv, you will need to change the values in
  configuration.ino to set the exact pins the drivers are wired up to.
  
*/


// 1. Specify what kind of controller board you are using
// ======================================================
// UNO or MEGA. Uncomment the line for the kind of board you have.
#ifndef MICROCONTROLLER
#define MICROCONTROLLER MC_UNO
//#define MICROCONTROLLER MC_MEGA
#endif


// 2. Add some libraries if you have a MEGA
// ========================================
// Uncomment the SPI and SD lines below if you have a MEGA.  
// http://forum.arduino.cc/index.php?topic=173584.0
//#include <SPI.h>
//#include <SD.h>


// 3. Specify what kind of motor driver you are using
// ==================================================
// Only ONE set of lines below should be uncommented.

//   i. Adafruit Motorshield v1. The original, and still the best.
//   -------------------------------------------------------------
//#define ADAFRUIT_MOTORSHIELD_V1
//#include <AFMotor.h>

//   ii. Adafruit Motorshield v2. It's all squealy.
//   ----------------------------------------------
//#define ADAFRUIT_MOTORSHIELD_V2
//#include <Wire.h>
//#include <Adafruit_MotorShield.h>
//#include "utility/Adafruit_PWMServoDriver.h"

//   iii. Using discrete stepper drivers? (eg EasyDriver, stepstick, Pololu gear)
//   ----------------------------------------------------------------------------
//   Don't forget to define your pins in 'configuration.ino'.
#define SERIAL_STEPPER_DRIVERS 

//   iv. Using a signal amplifier like a UNL2003? 
//   --------------------------------------------
//   Don't forget to define your pins in 'configuration.ino'.
//   #define UNL2003_DRIVER


// 4.  Turn on some debugging code if you want horror
// =================================================
//#define DEBUG
//#define DEBUG_COMMS
//#define DEBUG_PENLIFT
//#define DEBUG_PIXEL


// 5.  Disable program features if you need to free up space
// ========================================================
#define PIXEL_DRAWING
#define PENLIFT
#define VECTOR_LINES



/*  ===========================================================  
    These variables are common to all polargraph server builds
=========================================================== */    

// ==========================================================
// Some microcontroller's names
#define MC_UNO 1
#define MC_MEGA 2

#include <AccelStepper.h>
#include <Servo.h>
#include <EEPROM.h>
#include "EEPROMAnything.h"

const String FIRMWARE_VERSION_NO = "1.2.1";

//  EEPROM addresses
const byte EEPROM_MACHINE_WIDTH = 0;
const byte EEPROM_MACHINE_HEIGHT = 2;
const byte EEPROM_MACHINE_MM_PER_REV = 14; // 4 bytes (float)
const byte EEPROM_MACHINE_STEPS_PER_REV = 18;
const byte EEPROM_MACHINE_STEP_MULTIPLIER = 20;

const byte EEPROM_MACHINE_MOTOR_SPEED = 22; // 4 bytes float
const byte EEPROM_MACHINE_MOTOR_ACCEL = 26; // 4 bytes float
const byte EEPROM_MACHINE_PEN_WIDTH = 30; // 4 bytes float

const byte EEPROM_MACHINE_HOME_A = 34; // 4 bytes
const byte EEPROM_MACHINE_HOME_B = 38; // 4 bytes

const byte EEPROM_PENLIFT_DOWN = 42; // 2 bytes
const byte EEPROM_PENLIFT_UP = 44; // 2 bytes

// Pen raising servo
Servo penHeight;
const int DEFAULT_DOWN_POSITION = 90;
const int DEFAULT_UP_POSITION = 180;
static int upPosition = DEFAULT_UP_POSITION; // defaults
static int downPosition = DEFAULT_DOWN_POSITION;
static int penLiftSpeed = 3; // ms between steps of moving motor
const byte PEN_HEIGHT_SERVO_PIN = A3; //Change the servo pin to A3, to pass through to the coolant enable pin.
boolean isPenUp = false;

// Machine specification defaults
const int DEFAULT_MACHINE_WIDTH = 650;
const int DEFAULT_MACHINE_HEIGHT = 650;
const int DEFAULT_MM_PER_REV = 95;
const int DEFAULT_STEPS_PER_REV = 400;
const int DEFAULT_STEP_MULTIPLIER = 1;

// working machine specification
static int motorStepsPerRev = DEFAULT_STEPS_PER_REV;
static float mmPerRev = DEFAULT_MM_PER_REV;
static byte stepMultiplier = DEFAULT_STEP_MULTIPLIER;
static int machineWidth = DEFAULT_MACHINE_WIDTH;
static int machineHeight = DEFAULT_MACHINE_HEIGHT;


static float currentMaxSpeed = 800.0;
static float currentAcceleration = 400.0;
static boolean usingAcceleration = true;

int startLengthMM = 800;

float mmPerStep = 0.0F;
float stepsPerMM = 0.0F;

long pageWidth = machineWidth * stepsPerMM;
long pageHeight = machineHeight * stepsPerMM;
long maxLength = 0;

//static char rowAxis = 'A';
const int INLENGTH = 50;
const char INTERMINATOR = 10;
const char SEMICOLON = ';';

float penWidth = 0.8F; // line width in mm

boolean reportingPosition = true;
boolean acceleration = true;

extern AccelStepper motorA;
extern AccelStepper motorB;

boolean currentlyRunning = true;

static char inCmd[10];
static char inParam1[14];
static char inParam2[14];
static char inParam3[14];
static char inParam4[14];

static byte inNoOfParams;

char lastCommand[INLENGTH+1];
boolean commandConfirmed = false;

int rebroadcastReadyInterval = 5000;
long lastOperationTime = 0L;
long motorIdleTimeBeforePowerDown = 600000L;
boolean automaticPowerDown = true;
boolean powerIsOn = false;

long lastInteractionTime = 0L;

#ifdef PIXEL_DRAWING
static boolean lastWaveWasTop = true;

//  Drawing direction
const static byte DIR_NE = 1;
const static byte DIR_SE = 2;
const static byte DIR_SW = 3;
const static byte DIR_NW = 4;

static int globalDrawDirection = DIR_NW;

const static byte DIR_MODE_AUTO = 1;
const static byte DIR_MODE_PRESET = 2;
static byte globalDrawDirectionMode = DIR_MODE_AUTO;
#endif

#if MICROCONTROLLER == MC_MEGA
  #define READY_STR "READY_100"
#else
  #define READY_STR "READY"
#endif

#define RESEND_STR "RESEND"
#define DRAWING_STR "DRAWING"
#define OUT_CMD_SYNC_STR "SYNC,"

char MSG_E_STR[] = "MSG,E,";
char MSG_I_STR[] = "MSG,I,";
char MSG_D_STR[] = "MSG,D,";

const static char COMMA[] = ",";
const static char CMD_END[] = ",END";
const static String CMD_CHANGELENGTH = "C01";
const static String CMD_CHANGEPENWIDTH = "C02";
#ifdef PIXEL_DRAWING
const static String CMD_DRAWPIXEL = "C05";
const static String CMD_DRAWSCRIBBLEPIXEL = "C06";
const static String CMD_CHANGEDRAWINGDIRECTION = "C08";
const static String CMD_TESTPENWIDTHSQUARE = "C11";
#endif
const static String CMD_SETPOSITION = "C09";
#ifdef PENLIFT
const static String CMD_PENDOWN = "C13";
const static String CMD_PENUP = "C14";
const static String CMD_SETPENLIFTRANGE = "C45";
#endif
#ifdef VECTOR_LINES
const static String CMD_CHANGELENGTHDIRECT = "C17";
#endif
const static String CMD_SETMACHINESIZE = "C24";
const static String CMD_GETMACHINEDETAILS = "C26";
const static String CMD_RESETEEPROM = "C27";
const static String CMD_SETMACHINEMMPERREV = "C29";
const static String CMD_SETMACHINESTEPSPERREV = "C30";
const static String CMD_SETMOTORSPEED = "C31";
const static String CMD_SETMOTORACCEL = "C32";
const static String CMD_SETMACHINESTEPMULTIPLIER = "C37";

void setup() 
{
  Serial.begin(57600);           // set up Serial library at 57600 bps
  Serial.println("POLARGRAPH ON!");
  Serial.print("Hardware: ");
  Serial.println(MICROCONTROLLER);
  
  #if MICROCONTROLLER == MC_MEGA
  Serial.println("MC_MEGA");
  #elif MICROCONTROLLER == MC_UNO
  Serial.println("MC_UNO");
  #else
  Serial.println("No MC");
  #endif
  configuration_motorSetup();
  eeprom_loadMachineSpecFromEeprom();
  configuration_setup();

  motorA.setMaxSpeed(currentMaxSpeed);
  motorA.setAcceleration(currentAcceleration);  
  motorB.setMaxSpeed(currentMaxSpeed);
  motorB.setAcceleration(currentAcceleration);
  
  float startLength = ((float) startLengthMM / (float) mmPerRev) * (float) motorStepsPerRev;
  motorA.setCurrentPosition(startLength);
  motorB.setCurrentPosition(startLength);
  for (int i = 0; i<INLENGTH; i++) {
    lastCommand[i] = 0;
  }    
  comms_ready();

#ifdef PENLIFT
  penlift_penUp();
#endif
  delay(500);

}

void loop()
{
  if (comms_waitForNextCommand(lastCommand)) 
  {
#ifdef DEBUG_COMMS    
    Serial.print(F("Last comm: "));
    Serial.print(lastCommand);
    Serial.println(F("..."));
#endif
    comms_parseAndExecuteCommand(lastCommand);
  }
}

#if MICROCONTROLLER == MC_MEGA
const static String CMD_TESTPENWIDTHSCRIBBLE = "C12";
const static String CMD_DRAWSAWPIXEL = "C15,";
const static String CMD_DRAWCIRCLEPIXEL = "C16";
const static String CMD_SET_ROVE_AREA = "C21";
const static String CMD_DRAWDIRECTIONTEST = "C28";
const static String CMD_MODE_STORE_COMMANDS = "C33";
const static String CMD_MODE_EXEC_FROM_STORE = "C34";
const static String CMD_MODE_LIVE = "C35";
const static String CMD_RANDOM_DRAW = "C36";
const static String CMD_START_TEXT = "C38";
const static String CMD_DRAW_SPRITE = "C39";
const static String CMD_CHANGELENGTH_RELATIVE = "C40";
const static String CMD_SWIRLING = "C41";
const static String CMD_DRAW_RANDOM_SPRITE = "C42";
const static String CMD_DRAW_NORWEGIAN = "C43";
const static String CMD_DRAW_NORWEGIAN_OUTLINE = "C44";

/*  End stop pin definitions  */
const int ENDSTOP_X_MAX = 17;
const int ENDSTOP_X_MIN = 16;
const int ENDSTOP_Y_MAX = 15;
const int ENDSTOP_Y_MIN = 14;

long ENDSTOP_X_MIN_POSITION = 130;
long ENDSTOP_Y_MIN_POSITION = 130;

// size and location of rove area
long rove1x = 1000;
long rove1y = 1000;
long roveWidth = 5000;
long roveHeight = 8000;

boolean swirling = false;
String spritePrefix = "";
int textRowSize = 200;
int textCharSize = 180;

boolean useRoveArea = false;

int commandNo = 0;
int errorInjection = 0;

boolean storeCommands = false;
boolean drawFromStore = false;
String commandFilename = "";

// sd card stuff
const int chipSelect = 53;
boolean sdCardInit = false;

// set up variables using the SD utility library functions:
File root;
boolean cardPresent = false;
boolean cardInit = false;
boolean echoingStoredCommands = false;

// the file itself
File pbmFile;

// information we extract about the bitmap file
long pbmWidth, pbmHeight;
float pbmScaling = 1.0;
int pbmDepth, pbmImageoffset;
long pbmFileLength = 0;
float pbmAspectRatio = 1.0;

volatile int speedChangeIncrement = 100;
volatile int accelChangeIncrement = 100;
volatile float penWidthIncrement = 0.05;
volatile int moveIncrement = 400;

boolean currentlyDrawingFromFile = false;
String currentlyDrawingFilename = "";

static float translateX = 0.0;
static float translateY = 0.0;
static float scaleX = 1.0;
static float scaleY = 1.0;
static int rotateTransform = 0;

#endif

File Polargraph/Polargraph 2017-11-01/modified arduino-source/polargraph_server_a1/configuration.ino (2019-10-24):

/**
*  Polargraph Server. - CORE
*  Written by Sandy Noble
*  Released under GNU License version 3.
*  http://www.polargraph.co.uk
*  https://github.com/euphy/polargraph_server_a1

Configuration.

This is one of the core files for the polargraph server program.  
It sets up the motor objects (AccelSteppers), and has default
values for the motor, sprocket and microstepping combinations used
by polargraphs so far.
*/

#ifdef ADAFRUIT_MOTORSHIELD_V1
const int stepType = INTERLEAVE;
AF_Stepper afMotorA(motorStepsPerRev, 1);
AF_Stepper afMotorB(motorStepsPerRev, 2);

void forwarda() { afMotorA.onestep(FORWARD, stepType); }
void backwarda() { afMotorA.onestep(BACKWARD, stepType); }
void forwardb() { afMotorB.onestep(FORWARD, stepType); }
void backwardb() { afMotorB.onestep(BACKWARD, stepType); }

AccelStepper motorA(forwarda, backwarda);
AccelStepper motorB(forwardb, backwardb);
#endif

#ifdef ADAFRUIT_MOTORSHIELD_V2
const int stepType = MICROSTEP;

Adafruit_MotorShield AFMS = Adafruit_MotorShield(); 
Adafruit_StepperMotor *afMotorA = AFMS.getStepper(motorStepsPerRev, 1);
Adafruit_StepperMotor *afMotorB = AFMS.getStepper(motorStepsPerRev, 2);

void forwarda() { afMotorA->onestep(FORWARD, stepType); }
void backwarda() { afMotorA->onestep(BACKWARD, stepType); }
void forwardb() { afMotorB->onestep(FORWARD, stepType); }
void backwardb() { afMotorB->onestep(BACKWARD, stepType); }
AccelStepper motorA(forwarda, backwarda);
AccelStepper motorB(forwardb, backwardb);
#endif

/* Motor setup if you are using serial stepper drivers 
(EasyDrivers, stepsticks, Pololu etc).

If you are wiring up yourself, just put the pin numbers in here.

Note that the pen lift servo usually lives on pin 9, so avoid 
that if you can. If you can't, then you know how to change it.
*/
#ifdef SERIAL_STEPPER_DRIVERS
#define MOTOR_A_ENABLE_PIN 8
#define MOTOR_A_STEP_PIN 2
#define MOTOR_A_DIR_PIN 5
  
#define MOTOR_B_ENABLE_PIN 4
#define MOTOR_B_STEP_PIN 3
#define MOTOR_B_DIR_PIN 6
AccelStepper motorA(1,MOTOR_A_STEP_PIN, MOTOR_A_DIR_PIN); 
AccelStepper motorB(1,MOTOR_B_STEP_PIN, MOTOR_B_DIR_PIN); 
#endif

#ifdef UNL2003_DRIVER
// Contributed by @j0nson
// Initialize ULN2003 stepper driver
// first number is type of stepper motor, 4 for a normal 4 wire step motor, 8 for a halfstepped normal 4 wire motor
//Connection Directions
// MotorA
//ULN2003  Arduino  AcceStepper Init
//IN1      2        2
//IN2      3        4
//IN3      4        3
//IN4      5        5
// MotorB
//ULN2003  Arduino  AcceStepper Init
//IN1      6        6
//IN2      7        8
//IN3      8        7
//IN4      9        9

//for a 28YBJ-48 Stepper, change these parameters above
//Step angle (8-step) 5.625deg, 64 steps per rev
//Step angle (4-step) 11.25deg, 32 steps per rev
//gear reduction ratio 1/63.68395

// motorStepsPerRev = 32 * 63.68395 = 2038; //for 4 step sequence
// motorStepsPerRev = 64 * 63.68395 = 4076; //for 8 step sequence

// motorStepsPerRev = 4076;
// mmPerRev = 63;
// DEFAULT_STEPS_PER_REV = 4076;
// DEFAULT_MM_PER_REV = 63;

AccelStepper motorA(8, 6,8,7,9);
AccelStepper motorB(8, 2,4,3,5);
#endif

void configuration_motorSetup()
{
#ifdef SERIAL_STEPPER_DRIVERS
  pinMode(MOTOR_A_ENABLE_PIN, OUTPUT);
  digitalWrite(MOTOR_A_ENABLE_PIN, HIGH);
  pinMode(MOTOR_B_ENABLE_PIN, OUTPUT);
  digitalWrite(MOTOR_B_ENABLE_PIN, HIGH);
  motorA.setEnablePin(MOTOR_A_ENABLE_PIN);
  motorA.setPinsInverted(false, false, true);
  motorB.setEnablePin(MOTOR_B_ENABLE_PIN);
  motorB.setPinsInverted(true, false, true); // this one turns the opposite direction to A, hence inverted.
#endif
}

void configuration_setup()
{
  mmPerStep = mmPerRev / multiplier(motorStepsPerRev);
  stepsPerMM = multiplier(motorStepsPerRev) / mmPerRev;
  
#ifdef ADAFRUIT_MOTORSHIELD_V2
  AFMS.begin();  // create with the default frequency 1.6KHz
#endif
  delay(500);
  
}
// end of Adafruit motorshield definition
// =================================================================

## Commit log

2019-10-06 Add files via upload
    Phase 1 Models used for testing
    - Gondola is made up of 4 parts and extended hard mounted arms should make testing easier
    [Gondola.STL, MotorMount.stl]
2019-10-06 Polargraph Software
    Software package to turn SVG images into usable Gcode via Arduino IDE.
    - Includes source code (Software / arduino-source)
    - Includes libraries needed for Arduino IDE (Software / arduino-source / libraries)
    - Includes ino files for sketchbook (Software / arduino-source / polargraph_server_a1)
    - Includes JRE polargraph controller to make configuration quick and easy
2019-10-06 .STL Files
    Models for phase 1 of 3D printing
    Includes more parts for testing and rigidity compared to final product
2019-10-06 JoyToKeyToPlotter
    .CFG file used to turn gamepad commands into effectively Gcode, utilizing GRBL's 'jogger' functionality
    How it Works:
    By pushing a direction, 2 commands are sent to both motors of the plotter to make the gondola move in a specific direction.
    --Cheat Sheet for movement--
    Left Motor = X
    Right Motor = Y
    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
    [JoyToKeyToPlotter.cfg]
2019-10-06 Wiring Diagram for the IPAD
    Utilizing a Rasp Pi to Arduino and CNC Shield
2019-10-19 Polargraph software
    Includes:
    Modified arduino firmware
    Built controller software from source with java included
    [cars2.tsv, chair.obj, data.csv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]
2019-10-24 Added Custom Firmware
    Added the custom Polargraph Arduino firmware, modified for use with the Protoneer
2019-10-25 Updated Arduino Firmware
    Renamed files, removed obsolete builds
2019-10-25 Updated Arduino Firmware
    Modified the pen lift output to use pin A3 instead of 9. This allows the signal to pass through the Protoneetr Stepper Motor Controller, out through the Coolant Enable pins to the servo
2019-10-26 Updated Arduino Firmware
    Added updated Arduino firmware
2019-10-30 Update machine config
    Fine tuned measurements and home location, as well as motor speed
